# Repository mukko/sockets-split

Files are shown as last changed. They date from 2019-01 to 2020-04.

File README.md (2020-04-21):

# Sockets Split Keyboard

このデータで生産しても、一切の責任を負いません。  

# zinc keyboardを推奨しています

つくりがしっかりとしていて、価格も安く素敵なzincキーボードを推奨しています。  
https://booth.pm/ja/items/1076720

## 特徴

このキーボードは `左右対称配列`であり、 `スイッチソケット専用`、 `ProMicroスプリングピンヘッダ対応`をした 両手で`48キー`のキーボードです。 
あまり見かけないこの配列にまずはシンプルに入門できればよいと考え、またNext Let's splitとして作成しました。  
  
はんだ付けの難易度は、表面実装の部品があるため若干難しめと考えています。  
表面実装部品はソケットとダイオードです。それらのはんだ付けの練習キットとしてもいいかもしれません。  

ProMicroの結線はLet's split rev2に準拠しており、もしお使いの場合そのキーマップをそのまま利用することが可能です。  

## rev1.2, 1.3の諸注意
ケース、スイッチ組み立てページに記載しています。

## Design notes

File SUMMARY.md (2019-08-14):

# Summary

* [はじめに](README.md)
* [セット内容と必要なもの](./docs/01-set.md)
* [PCB組み立て](./docs/02-soldering.md)
* [ケース、スイッチ組み立て](./docs/03-case.md)
* [ファームウェアビルド、書き込み](./docs/04-firmware.md)

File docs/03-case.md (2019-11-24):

# ケース、スイッチ組み立て

PCBの四隅と間に4つの穴が空いていると思いますが、外周四隅をスペーサーとネジで止めていきます。  

1. アクリルの保護シートを剥がします
2. 向きを確認します。下側アクリルの凹みの向きがpromicroと同じ向きかどうかを確認します
3. キースイッチを基板の穴の向きに合わせて上側のアクリルとソケットに挿し込みます
4. 片手24キーをすべて終えたら四隅にスペーサーをネジで止めます
5. 下側のアクリルの位置を合わせ、スペーサーをネジ止めします

以上の手順を両手分行うと、キーボードの筐体は完成です。残りはファームウェアの書き込みです！

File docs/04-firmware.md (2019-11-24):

# ファームウェア書き込み

## リポジトリ

qmk_firmwareを利用していますが、まだ本家の方へのPull Reqeusを発行していないため、以下のリポジトリから取得してください。  
[mukkoのqmk_firmware](https://github.com/mukko/qmk_firmware)  

## 書き込み

PCとケーブルで接続し、片手ずつ実行してください。  

[QMK Toolbox](https://github.com/qmk/qmk_toolbox/releases)を利用して書き込む。  
もしくは、qmk_firmwareのルートディレクトリで以下のコマンドでビルドします。  

```bash
# build
make sockets_split/rev1:default
```

書き込みまで一気にやる場合、  

```bash
# build and flush
make sockets_split/rev1:default:avrdude
```

USBケーブルでPCとキーボードを接続し、上記コマンドで生成したバイナリファイルを書き込みます。  
リセットスイッチを押すと書き込める状態なるので、その状態の際に書き込みを実行してください。

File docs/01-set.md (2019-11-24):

# キット内容

|名前|個数|
|:--:|:--:|
| PCB | 2枚 |
| トッププレート | 2枚 |
| ボトムプレート | 2枚 |
| ダイオード（1N4148W） | 50個 |
| 4極ジャック（MJ-4PP-9） | 2個 |
| kailh MX互換スイッチ用PCBソケット | 50個 |
| リセット用タクトスイッチ | 2個 |
| ねじ | 16個 |
| スペーサー | 8個 |
| ゴム足 | 8個 |

以下は付属しないため、各自ご用意をお願いします。  
オプション以外のものは必須です。  

|名前|個数|
|:--:|:--:|
| キースイッチ | 48個 |
| キーキャップ（1U）| 48個 |
| ProMicro | 2個 |
| TRRSケーブル | 1本 |
| microB USBケーブル | 1本 |
| （推奨オプション）ProMicro用スプリングピンヘッダ | 2セット |
| （オプション）Underglowテープ | 2個 |

## 必要な工具

- はんだごて
- はんだ
- +ドライバー

作業の際には高温となりますので、やけどや換気に気を付けてください。  
はんだ付けについてから知りたい方は以下の有名はんだごてメーカーの白光さんのサイトをご覧ください。  
[外部リンク　はんだづけについて](http://handa-craft.hakko.com/)

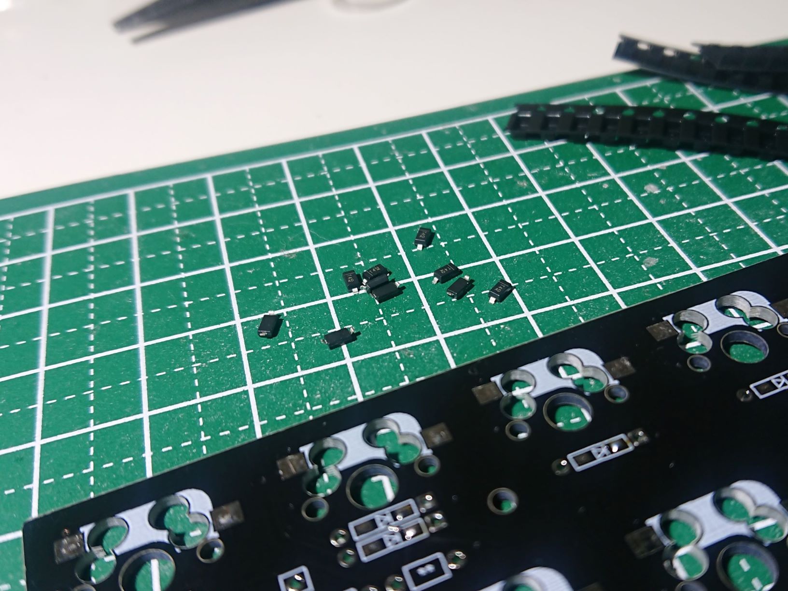
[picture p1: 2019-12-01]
docs/asset/img/diode.jpg

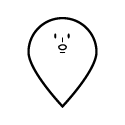
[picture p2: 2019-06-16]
silk2.png

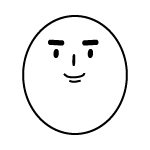
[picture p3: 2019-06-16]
silk1.png

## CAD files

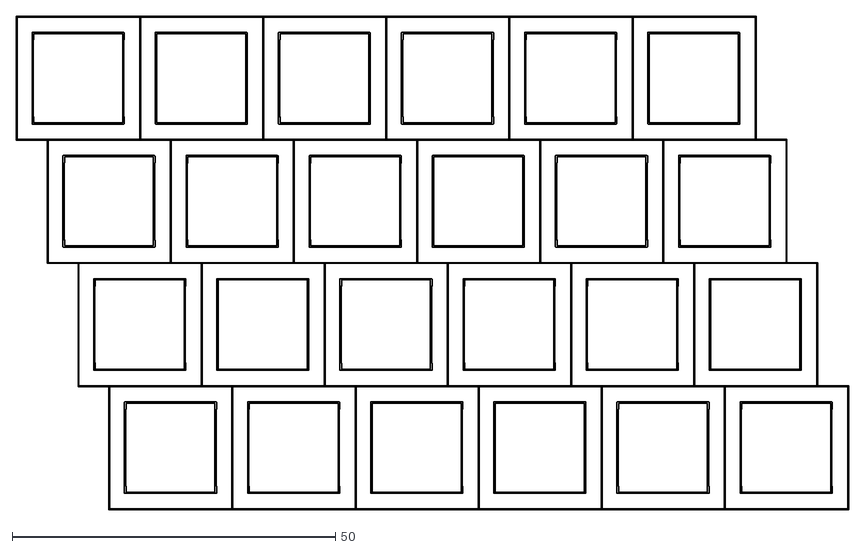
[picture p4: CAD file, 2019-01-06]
sockets-split-Dwgs.User.dxf
128.7 x 76.3

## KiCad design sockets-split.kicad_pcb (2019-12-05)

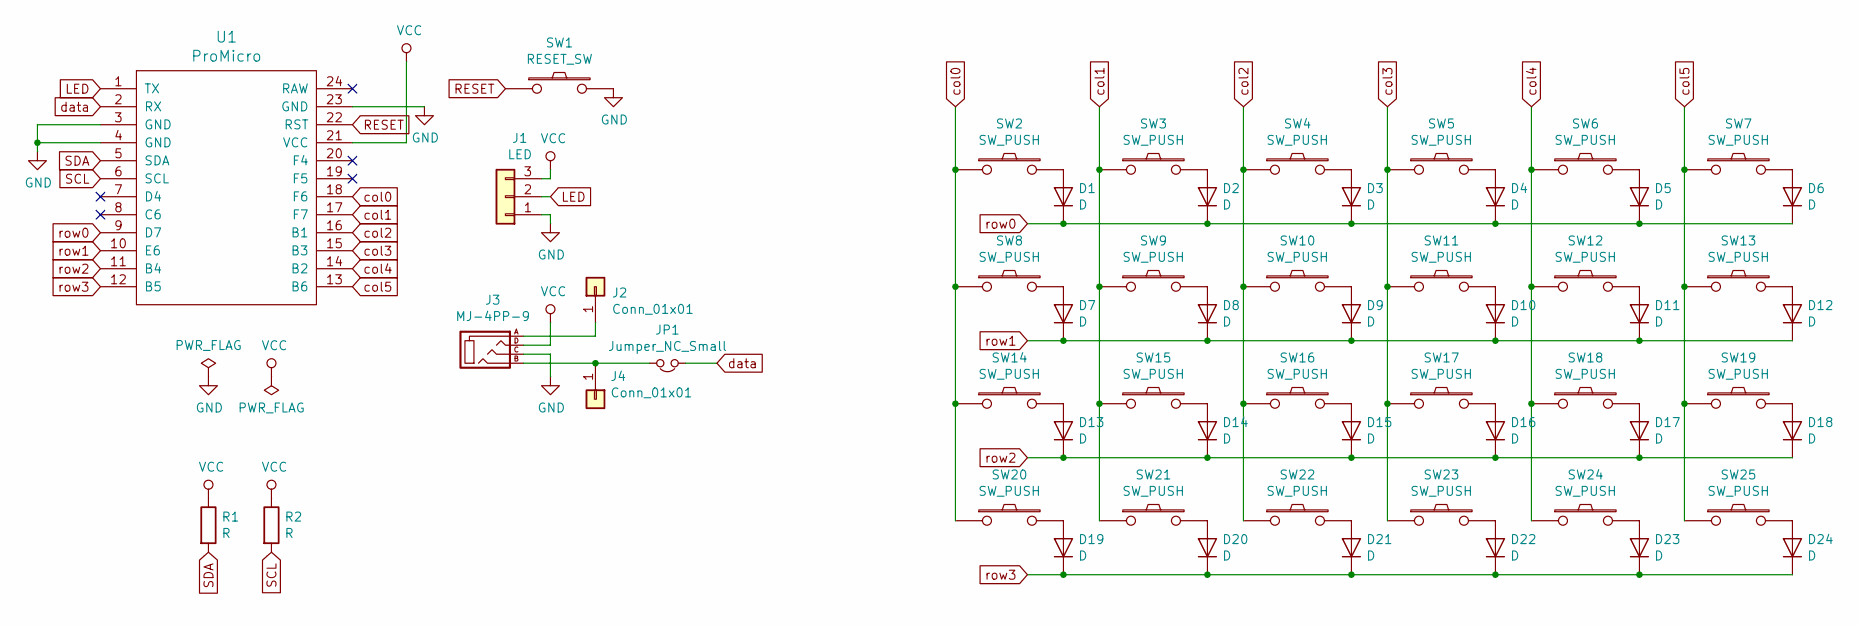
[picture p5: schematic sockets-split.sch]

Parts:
D1, D2, D3, D4, D5, D6, D7, D8, D9, D10, D11, D12, D13, D14, D15, D16, D17, D18, D19, D20, D21, D22, D23, D24: D; D3_TH_SMD
J1: LED; StripLED_rev
J2, J4: Conn_01x01; 1pin_conn
J3: MJ-4PP-9
JP1: Jumper_NC_Small; Jumper
R1, R2: R
SW1: RESET_SW; ResetSW_4P
SW2, SW3, SW4, SW5, SW6, SW7, SW8, SW9, SW10, SW11, SW12, SW13, SW14, SW15, SW16, SW17, SW18, SW19, SW20, SW21, SW22, SW23, SW24, SW25: SW_PUSH; CherryMX_Hotswap
U1: ProMicro; ProMicro_v2_one

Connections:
GND: J1.1, J2.C, J3.C, SW1.2, U1.3 (GND), U1.4 (GND), U1.23 (GND); also elsewhere on the board
LED: J1.2, U1.1 (TX); also elsewhere on the board
unnamed: D1.2 (A), SW2.2
unnamed: D2.2 (A), SW3.2
unnamed: D3.2 (A), SW4.2
unnamed: D4.2 (A), SW5.2
unnamed: D5.2 (A), SW6.2
unnamed: D6.2 (A), SW7.2
unnamed: D7.2 (A), SW8.2
unnamed: D8.2 (A), SW9.2
unnamed: D9.2 (A), SW10.2
unnamed: D10.2 (A), SW11.2
unnamed: D11.2 (A), SW12.2
unnamed: D12.2 (A), SW13.2
unnamed: D13.2 (A), SW14.2
unnamed: D14.2 (A), SW15.2
unnamed: D15.2 (A), SW16.2
unnamed: D16.2 (A), SW17.2
unnamed: D17.2 (A), SW18.2
unnamed: D18.2 (A), SW19.2
unnamed: D19.2 (A), SW20.2
unnamed: D20.2 (A), SW21.2
unnamed: D21.2 (A), SW22.2
unnamed: D22.2 (A), SW23.2
unnamed: D23.2 (A), SW24.2
unnamed: D24.2 (A), SW25.2
unnamed 26: J2.A; also elsewhere on the board
unnamed 27: J2.B; also elsewhere on the board
unnamed: J2.1, J3.A
unnamed: J3.B, J4.1, JP1.2
RESET: SW1.1, U1.22 (RST)
SCL: R2.2, U1.6 (SCL)
SDA: R1.2, U1.5 (SDA)
VCC: J1.3, J2.D, J3.D, R1.1, R2.1, U1.21 (VCC); also elsewhere on the board
col0: SW2.1, SW8.1, SW14.1, SW20.1, U1.18 (F6)
col1: SW3.1, SW9.1, SW15.1, SW21.1, U1.17 (F7)
col2: SW4.1, SW10.1, SW16.1, SW22.1, U1.16 (B1)
col3: SW5.1, SW11.1, SW17.1, SW23.1, U1.15 (B3)
col4: SW6.1, SW12.1, SW18.1, SW24.1, U1.14 (B2)
col5: SW7.1, SW13.1, SW19.1, SW25.1, U1.13 (B6)
data: JP1.1, U1.2 (RX)
row0: D1.1 (K), D2.1 (K), D3.1 (K), D4.1 (K), D5.1 (K), D6.1 (K), U1.9 (D7)
row1: D7.1 (K), D8.1 (K), D9.1 (K), D10.1 (K), D11.1 (K), D12.1 (K), U1.10 (E6)
row2: D13.1 (K), D14.1 (K), D15.1 (K), D16.1 (K), D17.1 (K), D18.1 (K), U1.11 (B4)
row3: D19.1 (K), D20.1 (K), D21.1 (K), D22.1 (K), D23.1 (K), D24.1 (K), U1.12 (B5)

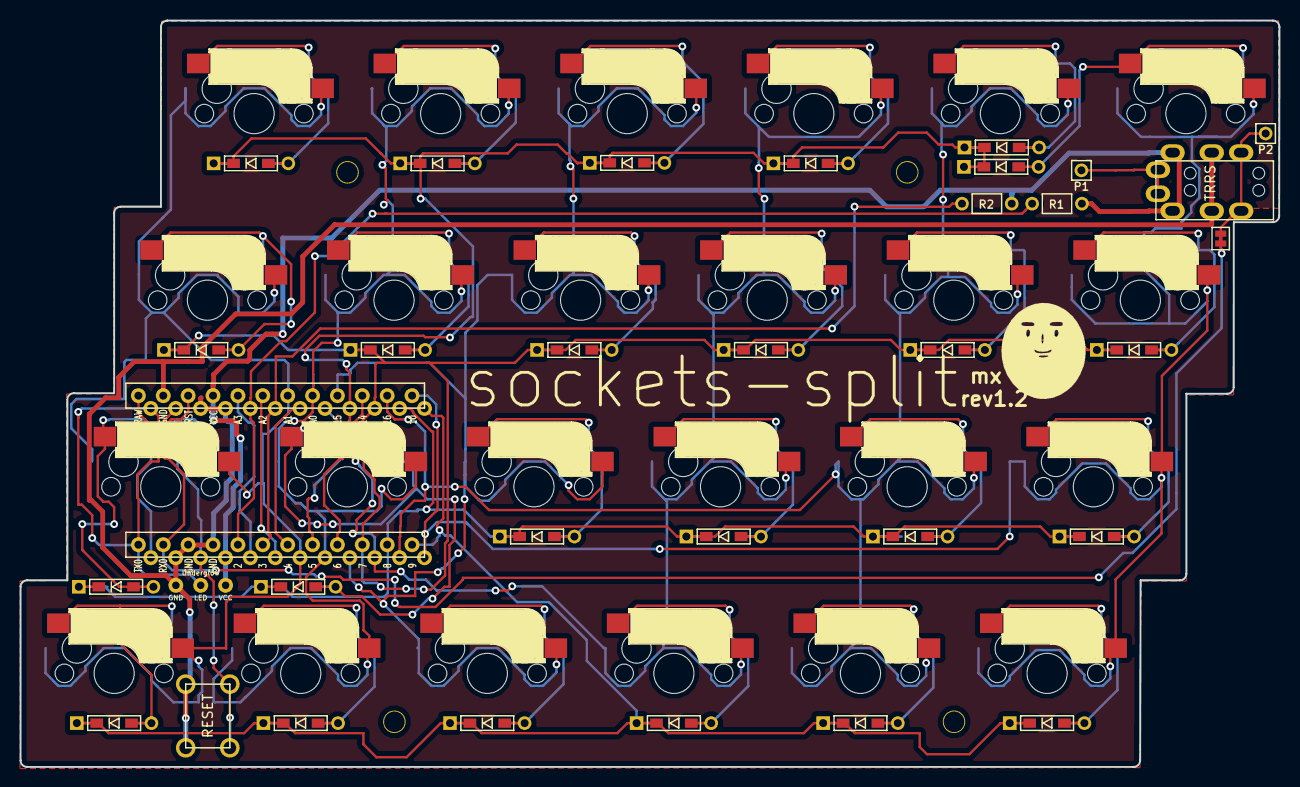
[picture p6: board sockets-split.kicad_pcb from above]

Board: 2 copper layers, 128.5 x 76.2 mm, 60 parts (0 on the bottom side), 42 nets.

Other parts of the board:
P1, P2: i2c-pin; 1pin_conn
Ref**: Val**; HOLE
Ref**#2, Ref**#3, Ref**#4: Val**; HOLE
Underglow: LED; StripLED_THT

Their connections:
GND: Underglow.1; also elsewhere on the board
LED: Underglow.2; also elsewhere on the board
unnamed 26: P1.1; also elsewhere on the board
unnamed 27: P2.1; also elsewhere on the board
VCC: Underglow.3; also elsewhere on the board

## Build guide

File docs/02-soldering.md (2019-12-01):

# PCB組み立て

このパートでははんだを利用するので大変危険です。注意して作業してください。  
組み立ては背の低いパーツから行います。  
背の低い順に

1. ダイオード
2. スイッチソケット
3. リセットスイッチ
4. ジャック
5. （オプション）UnderglowLED
6. ProMicro（ソケット付け）

## ダイオード

ダイオードには極性があるので向きに気を付けてはんだ付けしけてください。  

## スイッチソケット

ソケットを乗せる前に薄くはんだをつけておくとはんだ付けしやすいです。  
薄く乗せたはんだの上にソケットをしっかり差し込み再びしっかり温めてはんだ付けします。その際しっかりと差し込むようにしてください。  

## リセットスイッチ

向きに注意してはんだ付けしてください。  
はんだ付けした後の脚は、切らなくても大丈夫な想定ですが、切ったほうが確実にプレートに干渉しないです。  

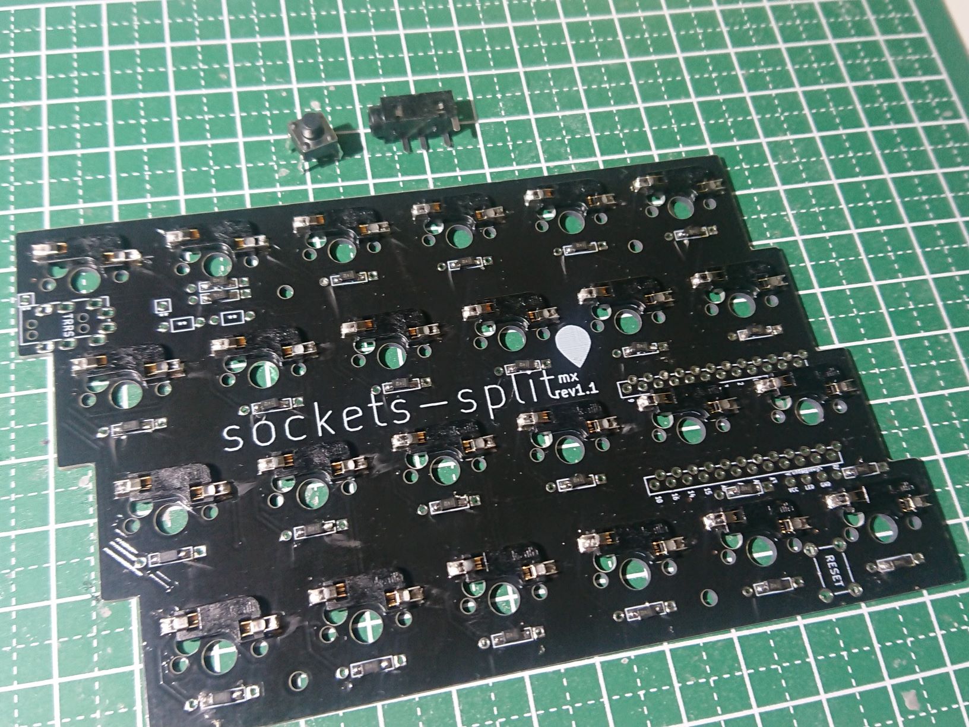
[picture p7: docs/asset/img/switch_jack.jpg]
リセットスイッチとジャックの位置


## ジャック

ダイオード、ソケットと同じ面に部品を載せ、はんだ付けしてください。  
はんだ付けした後の脚は、切らなくても大丈夫です。  

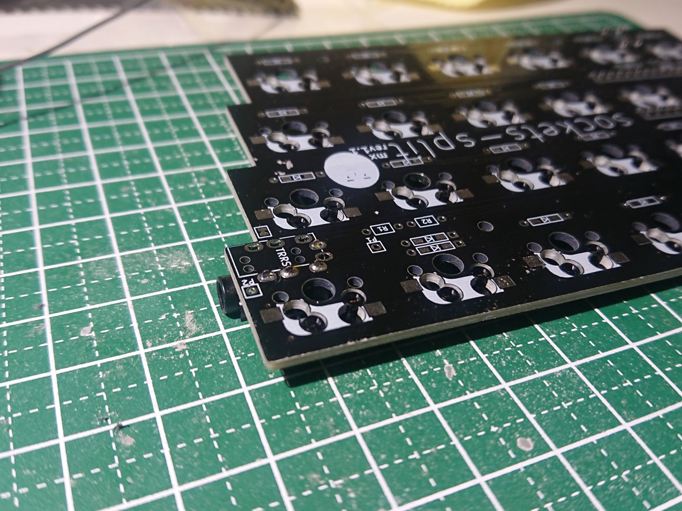
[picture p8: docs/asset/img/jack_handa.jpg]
ジャックはんだ


### (option)i2c

ジャック下のパッドがつながっている部分を
i2cを利用する際ははんだでつなげず、R1,R2にそれぞれ4.7kΩ抵抗をつけてください。  

## ProMicro

ProMicroに同梱されているピンヘッダでも構いませんが、 `抜き差しできる`コンスルーピンヘッダを使用する例を載せます。  
通常ProMicroに同梱されているピンヘッダでは裏側へのはんだ付けも必要になります。  
はんだ付けの面は両手とも以下の画像の向きで作成してください。  

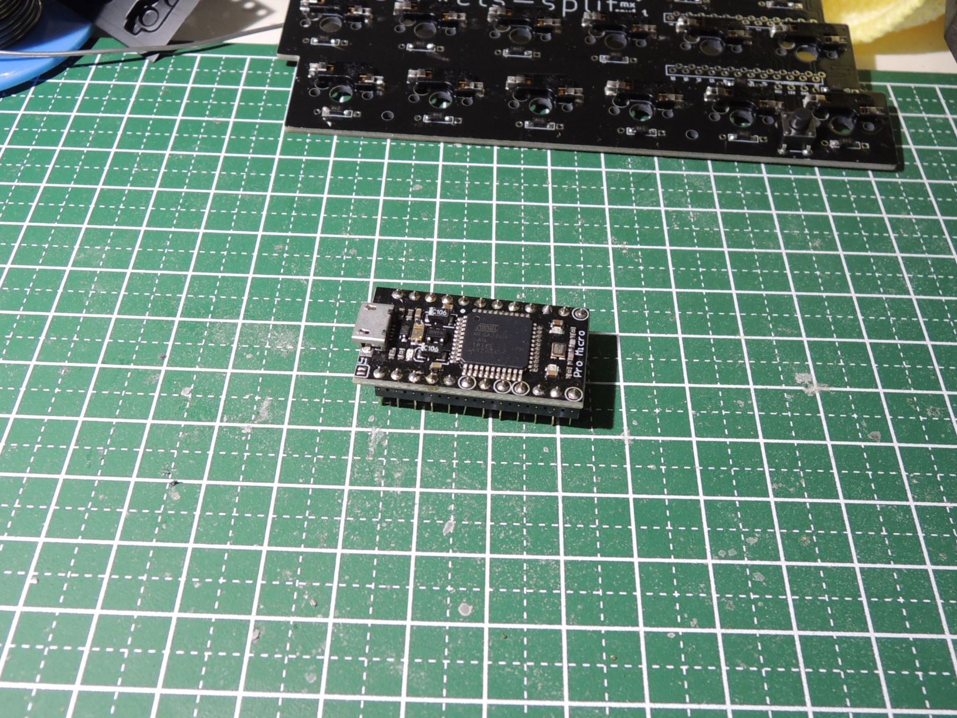
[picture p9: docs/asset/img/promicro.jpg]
promicroはんだ


基板にProMicroを載せます。  

向きはいろいろと実装されている方が表になるようにし、ピンヘッダを通したら表面をはんだ付けします。

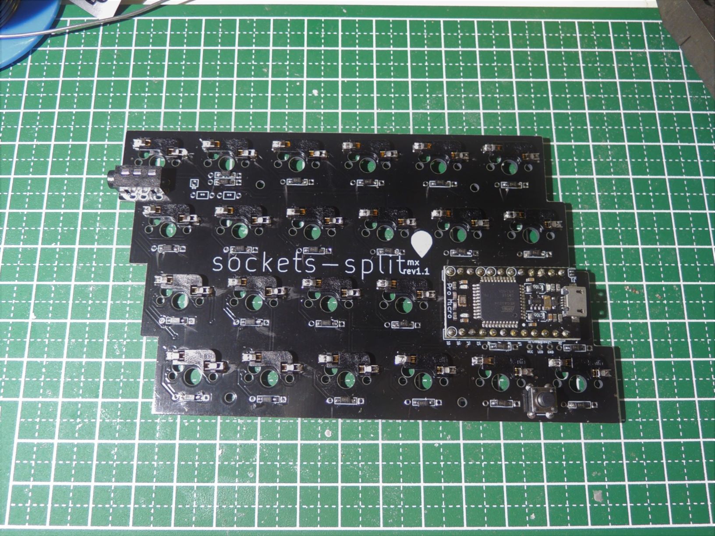
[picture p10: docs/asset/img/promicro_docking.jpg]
promicro取り付け


## わかってる人向けアウトレットキットを買われた方が必要な処理

### リード線等による結線

回路の結線が1箇所欠けてしまっていて、左右をつないで使用したときに、右手側の最下段が一切反応しません。  

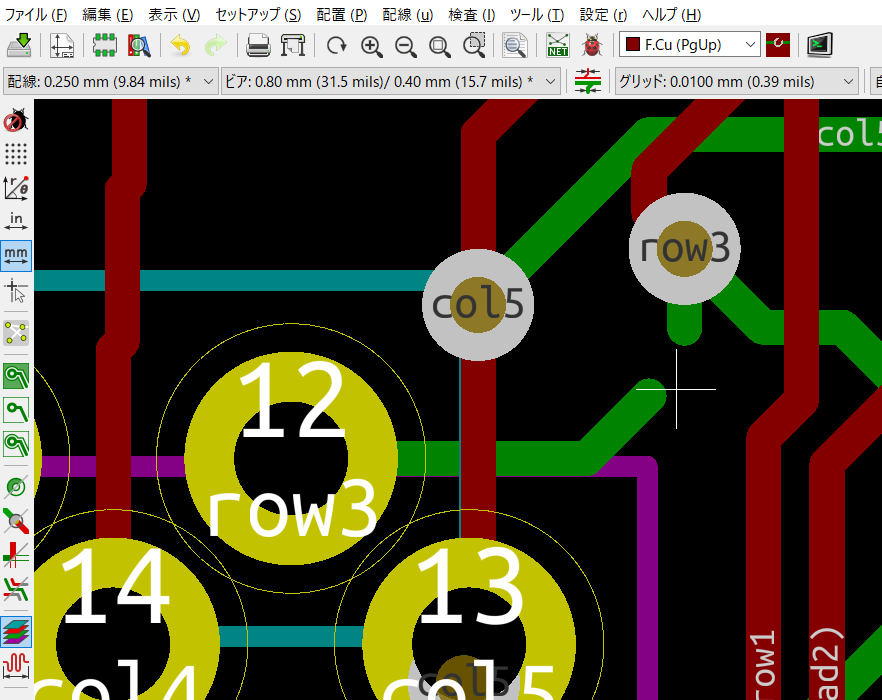
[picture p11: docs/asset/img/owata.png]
結線ミス


右手側基板の以下の画像に示す位置をリード線などで結線してください。これにより正常に使えるようになります。 
上側の二段目の一番右側と、下側一段目の一番右側です。  

注意点というか、難しいところはソケットが通る穴をふさがないように、フチにはんだ付けをすることです。  
もし難しい場合は、ここの足にだけ線をつなぎ、外す際にはその部分だけはんだを取る、などの運用でお願いします。  

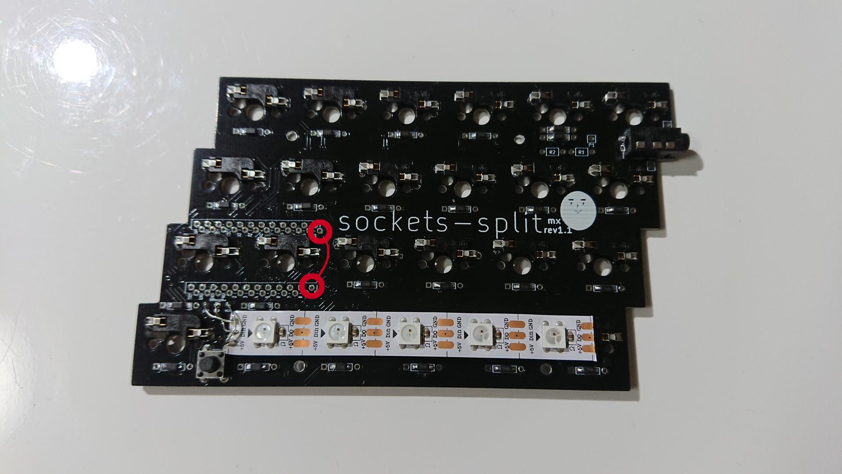
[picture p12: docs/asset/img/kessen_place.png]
結線箇所


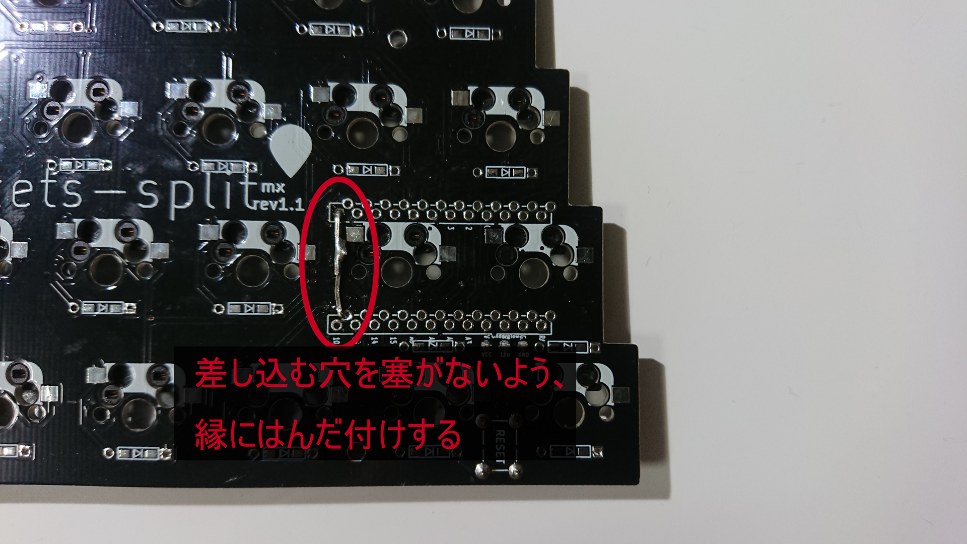
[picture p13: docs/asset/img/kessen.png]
結線例


## （オプション）UnderglowLED

基板のProMicroの下部にUnderglowLED用の配線をしてあります。  
LEDテープなどに対してそれぞれ対応した部分をはんだ付けしてください。LEDも向きが決まっているので注意してください。

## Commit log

2019-01-21 Add case
    [bottom_plate.scad, bottom_plate_v1.stl, sockets-split.kicad_pcb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]
2019-01-31 Fix JP to JPC
    [sockets-split.kicad_pcb]
2019-02-10 Add LEDをTHTのフットプリントにした
    [sockets-split.sch]
2019-02-11 Fix ネットリスト修正
    [sockets-split.kicad_pcb, sockets-split.sch]
2019-02-18 再配線開始
    [sockets-split-left.dxf, sockets-split.kicad_pcb, sockets-split.sch]
2019-02-18 Add Underglow text & set diode
    [sockets-split.kicad_pcb]
2019-02-19 [WIP]配線中
    [sockets-split.kicad_pcb]
2019-02-19 キースイッチとpromicro配線できた
    [sockets-split.kicad_pcb]
2019-03-05 Add GNDべた
    [sockets-split.kicad_pcb]
2019-03-13 Add rev1
    [sockets-split-Edge.Cuts.dxf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]
2019-04-13 Fix module & draw case line
    [sockets-split.kicad_pcb, sockets-split.sch]
2019-04-15 Fix promicro, case
    [sockets-split-B.Cu.gbl, sockets-split-B.Mask.gbs, sockets-split-B.SilkS.gbo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]
2019-06-16 Add gitbook
    [bottom_plate.scad, bottom_plate_v1.stl, case.dxf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]
2019-08-12 Update ドキュメント
2019-08-12 Fix SUMMARY
    [case.dxf]
2019-09-08 Fix promicro y + 2mm
    [sockets-split.kicad_pcb]
2019-11-02 Add bottom plate
    [sockets-split-bottom-plate.kicad_pcb, sockets-split-bottom-plate.sch, sockets-split-top-plate.kicad_pcb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]
2019-11-24 Add solder layer & Fix document
    [sockets-split-bottom-plate.kicad_pcb, sockets-split-top-plate.kicad_pcb]
2019-12-01 add docs images, fix pcb
    [sockets-split.kicad_pcb]
2019-12-04 一発で生産できなかったので、pcbの修正
    [sockets-split-bottom-plate.kicad_pcb, sockets-split-top-plate.kicad_pcb, sockets-split.kicad_pcb]
2019-12-05 穴を修正してみた
    [sockets-split-top-plate.kicad_pcb, sockets-split.kicad_pcb]
